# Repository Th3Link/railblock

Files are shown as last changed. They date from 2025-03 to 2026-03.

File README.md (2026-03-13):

# RailBlock

[]()
[]()

**RailBlock** is an open hardware CAN‑bus based block detector and
signal controller for model railways.

It is designed to integrate with a **Raspberry Pi running Rocrail**,
providing reliable **track occupancy detection** and **signal control**
using a distributed CAN bus network.

The project consists of:

-   **Hardware** -- KiCad PCB design
-   **Firmware** -- written in **Embedded Rust** using **Embassy** and
    **heapless**

------------------------------------------------------------------------

# Overview

RailBlock modules are connected using a **50 kbit/s CAN bus** carried
over **RJ45 cables**.\
Each board contains:

-   an **ESP32 microcontroller**
-   a **CAN transceiver**
-   inputs for **Hall sensors**
-   outputs for **signal lights**

Multiple boards can be connected in a **daisy-chain topology**,
distributing both **power (12V)** and **CAN communication** over a
single cable.

Typical setup:

    Raspberry Pi (Rocrail)
            │
       CAN Interface
            │
      ───── CAN Bus ─────
         │       │       │
     RailBlock RailBlock RailBlock
         │       │       │
     Sensors   Signals  Sensors

------------------------------------------------------------------------

# Features

-   CAN bus communication (**50 kbit/s**)
-   RJ45 bus connectors for **daisy chaining**
-   **Power + data on one cable**
-   Up to **3 Hall sensors** per board
-   Up to **7 signal outputs**
-   **ULN2003A sinking driver**
-   **ESP32 microcontroller**
-   **Embedded Rust firmware**
-   **JTAG debugging support**
-   Designed for **Rocrail integration**

------------------------------------------------------------------------

# Hardware

The hardware design is provided as a **KiCad project**.

Each RailBlock node contains:

-   ESP32 microcontroller
-   CAN transceiver
-   ULN2003A output driver
-   connectors for Hall sensors
-   connectors for signal lights
-   two RJ45 bus connectors

The RJ45 connectors allow the bus to **pass through each board**,
simplifying wiring.

Both **power and CAN signals** are carried through the same cable.

------------------------------------------------------------------------

# RJ45 Bus Pinout

RailBlock uses standard **RJ45 connectors** to distribute **CAN bus and
12V power**.

Multiple pins are paralleled to increase current capacity.

    RJ45 Pinout (RailBlock Bus)

       +-----------------------+
       | 1  2  3  4  5  6  7  8 |
       +-----------------------+

    Pin 1  ── GND
    Pin 2  ── GND
    Pin 3  ── GND

    Pin 4  ── CANH
    Pin 5  ── CANL

    Pin 6  ── +12V
    Pin 7  ── +12V
    Pin 8  ── +12V

Notes:

-   Pins **4 and 5 form a twisted pair** in standard Ethernet cables
    (blue / blue‑white).
-   Pins **1--3 and 6--8 are bundled** to increase current carrying
    capacity.
-   This allows moderate **power distribution along the bus**.

------------------------------------------------------------------------

# Bus Topology

RailBlock nodes must be connected in a **linear CAN topology**.

    12V + CAN Bus

    [Terminator] ── RailBlock ── RailBlock ── RailBlock ── [Terminator]

Important:

-   The **first and last node must be terminated**.
-   Termination uses the standard **120 Ω CAN resistor**.

------------------------------------------------------------------------

# Inputs -- Hall Sensors

Each RailBlock board supports **up to 3 Hall sensors** for track
occupancy detection.

Recommended sensor:

-   **TLE4905L**
-   or compatible digital Hall sensors

Typical setup:

-   a small magnet is mounted under a locomotive
-   the Hall sensor detects the magnet
-   the RailBlock node sends an occupancy event

Events are transmitted over CAN using **S88 event messages**.

------------------------------------------------------------------------

# Outputs -- Signals

Each RailBlock board supports **up to 7 signal outputs**.

Outputs are implemented using a **ULN2003A Darlington driver**.

The LED anode connects to **+12V or +5V via a resistor**, while the
RailBlock output sinks current. Some signals have internal resistors.

------------------------------------------------------------------------

# Firmware

The firmware is written in **Embedded Rust**.

Technologies used:

-   **Embassy** async runtime
-   **heapless** containers (no dynamic allocation)
-   **esp-hal**

Design goals:

-   deterministic behaviour
-   low memory usage
-   robust CAN communication

------------------------------------------------------------------------

# CAN Protocol

RailBlock communicates over CAN using two protocol types.

## Märklin CS2 Accessory Protocol

Used for:

-   signal control
-   accessory commands

## S88 Event Messages

Used to report:

-   Hall sensor triggers
-   block occupancy events

------------------------------------------------------------------------

# Programming and Debugging

The ESP32 firmware can be uploaded using:

### Programming Adapter

A dedicated **programming adapter** (separate project).

### JTAG

The board also supports **JTAG debugging**, allowing:

-   breakpoints
-   single stepping
-   real runtime debugging

------------------------------------------------------------------------

# Integration with Rocrail

RailBlock is designed to work with **Rocrail** running on a **Raspberry
Pi**.

Typical architecture:

    Raspberry Pi
       (Rocrail)
           │
       CAN Interface
           │
      ───── CAN Bus ─────
         │       │       │
     RailBlock RailBlock RailBlock
         │       │       │
     Sensors   Signals  Sensors

Rocrail can:

-   receive **occupancy events**
-   control **signals and accessories**

------------------------------------------------------------------------

# Repository Structure

    railblock/
    │
    ├─ firmware/        Embedded Rust firmware
    │
    ├─ hardware/        KiCad PCB design
    │
    ├─ docs/            Documentation
    │
    └─ README.md

------------------------------------------------------------------------

# Licensing

This repository contains both **hardware designs** and **software**.

## Firmware

Licensed under:

**GNU General Public License v3 (GPLv3)**

See:

    firmware/LICENSE.txt

## Hardware

Licensed under:

**CERN Open Hardware Licence Version 2 -- Strongly Reciprocal
(CERN-OHL-S-2.0)**

See:

    hardware/LICENSE.txt

------------------------------------------------------------------------

# Status

Early development.

Hardware and firmware are evolving together.

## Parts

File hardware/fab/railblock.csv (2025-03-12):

MPN |  | Manufacturer | Quantity | Designation
MCP1703A-5002E/DB | 500053801 | Microchip Technology | 1 | MCP1703Ax-500xxDB | U6
MCP1703A-3302E/DB | 500053800 | Microchip Technology | 1 | MCP1703Ax-330xxDB | U5
ULN2003A | 501429305 | UMW | 1 | ULN2003A | U4
ESP32-WROOM-32E-N4 | 500186636 | Espressif Systems | 1 | ESP32-WROOM-32 | U3
MCP2562-E/SN | 500054071 | Microchip Technology | 1 | MCP2562-E-SN | U2
PESD2CAN | 501716486 | DART | 1 | PESD2CAN | U1
RT0603FRE0727KL | 501355046 | YAGEO | 3 | 27K | R7,R5,R1
AA0603JR-0710KL | 501762420 | YAGEO | 3 | 10K | R6,R3,R2,R4
GRM188R71E104KA01D | 500015875 | Murata | 7 | 100n | C15,C12,C10,C9,C8,C4,C1
CL21B106KPQNNNG | 501368261 | Samsung Electro-Mechanics | 5 | 10u | C14,C13,C7,C6,C3
CL10B105KA8NFNC | 500024764 | Samsung Electro-Mechanics | 1 | 1u | C2

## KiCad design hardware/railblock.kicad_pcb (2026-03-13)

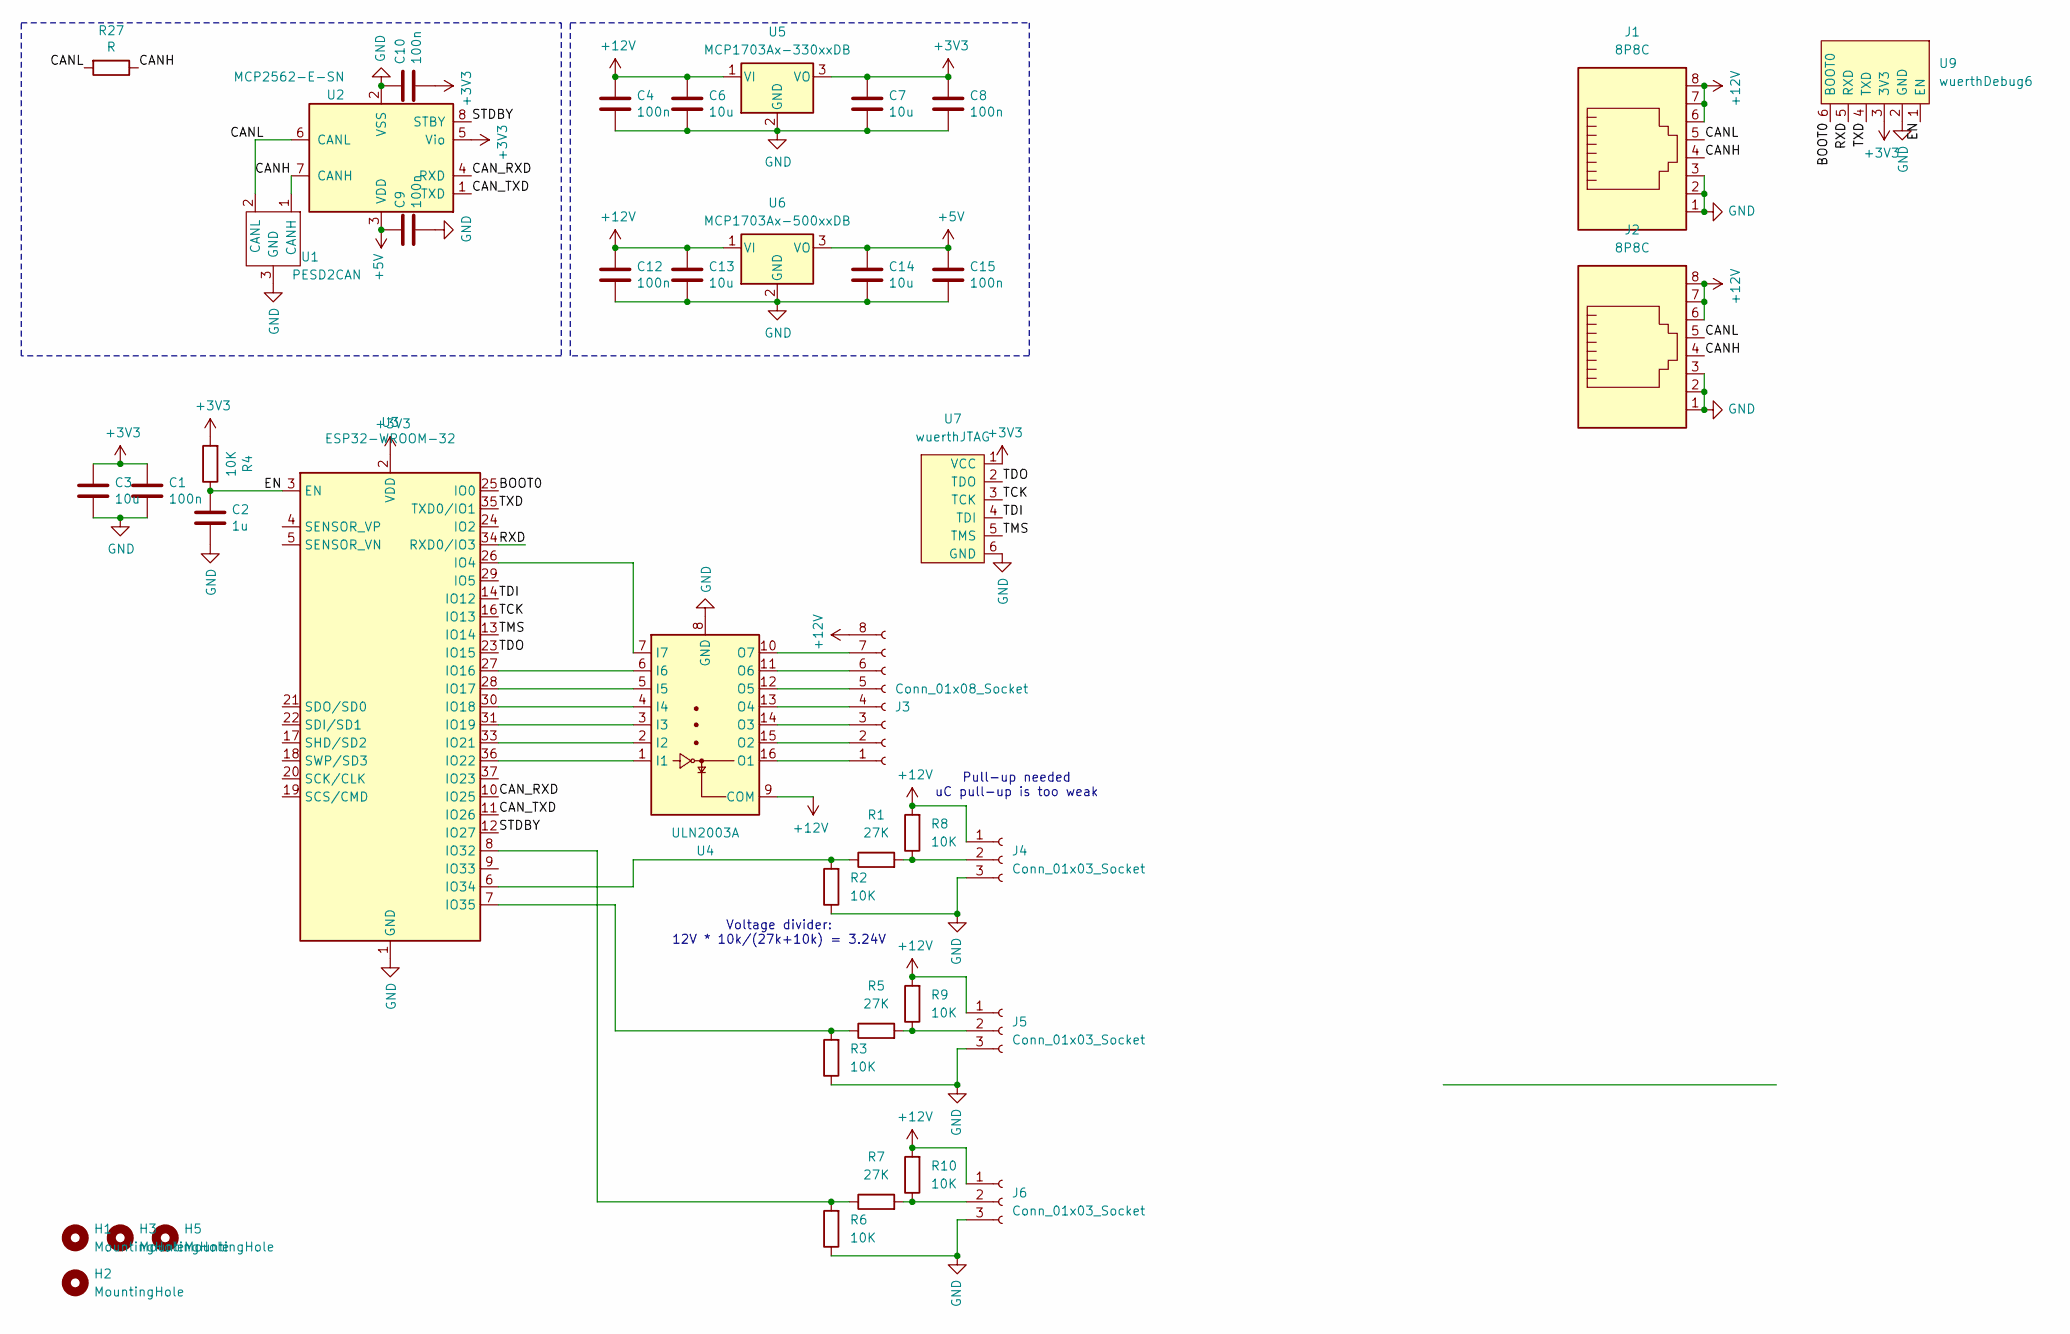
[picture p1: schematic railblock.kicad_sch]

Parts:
C1, C4, C8, C9, C10, C12, C15: 100n; C_0603_1608Metric_Pad1.08x0.95mm_HandSolder
C2: 1u; C_0603_1608Metric_Pad1.08x0.95mm_HandSolder
C3, C6, C7, C13, C14: 10u; C_0805_2012Metric_Pad1.18x1.45mm_HandSolder
H1, H2, H3, H5: MountingHole; MountingHole_3.2mm_M3_DIN965
J1, J2: 8P8C; RJ45_Ninigi_GE
J3: Conn_01x08_Socket; WAGO250-208
J4, J5, J6: Conn_01x03_Socket; WAGO250-203
R1, R5, R7: 27K; R_0603_1608Metric_Pad0.98x0.95mm_HandSolder
R2, R3, R4, R6, R8, R9, R10: 10K; R_0603_1608Metric_Pad0.98x0.95mm_HandSolder
R27: R; R_0603_1608Metric_Pad0.98x0.95mm_HandSolder
U1: PESD2CAN; SOT-23
U2: MCP2562-E-SN; SOIC-8_3.9x4.9mm_P1.27mm
U3: ESP32-WROOM-32
U4: ULN2003A; SOIC-16_3.9x9.9mm_P1.27mm
U5: MCP1703Ax-330xxDB; SOT-223-3_TabPin2
U6: MCP1703Ax-500xxDB; SOT-223-3_TabPin2
U7: wuerthJTAG
U9: wuerthDebug6

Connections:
+3V3: C1.1, C3.1, C7.1, C8.1, C10.1, R4.2, U2.5 (Vio), U3.2 (VDD), U5.3 (VO), U7.1 (VCC), U9.3 (3V3)
+5V: C9.1, C14.1, C15.1, U2.3 (VDD), U6.3 (VO)
+12V: C4.1, C6.1, C12.1, C13.1, J1.6, J1.7, J1.8, J2.6, J2.7, J2.8, J3.8, J4.1, J5.1, J6.1, R8.2, R9.2, R10.2, U4.9 (COM), U5.1 (VI), U6.1 (VI)
/BOOT0: U3.25 (IO0), U9.6 (BOOT0)
/CANH: J1.4, J2.4, R27.1, U1.1 (CANH), U2.7 (CANH)
/CANL: J1.5, J2.5, R27.2, U1.2 (CANL), U2.6 (CANL)
/CAN_RXD: U2.4 (RXD), U3.10 (IO25)
/CAN_TXD: U2.1 (TXD), U3.11 (IO26)
/EN: C2.1, R4.1, U3.3 (EN), U9.1 (EN)
/RXD: U3.34 (RXD0/IO3), U9.5 (RXD)
/STDBY: U2.8 (STBY), U3.12 (IO27)
/TCK: U3.16 (IO13), U7.3 (TCK)
/TDI: U3.14 (IO12), U7.4 (TDI)
/TDO: U3.23 (IO15), U7.2 (TDO)
/TMS: U3.13 (IO14), U7.5 (TMS)
/TXD: U3.35 (TXD0/IO1), U9.4 (TXD)
GND: C1.2, C2.2, C3.2, C4.2, C6.2, C7.2, C8.2, C9.2, C10.2, C12.2, C13.2, C14.2, C15.2, J1.1, J1.2, J1.3, J2.1, J2.2, J2.3, J4.3, J5.3, J6.3, R2.1, R3.1, R6.1, U1.3 (GND), U2.2 (VSS), U3.1 (GND), U3.15 (GND), U3.38 (GND), U3.39 (GND), U4.8 (GND), U5.2 (GND), U6.2 (GND), U7.6 (GND), U9.2 (GND)
unnamed: J3.1, U4.16 (O1)
unnamed: J3.2, U4.15 (O2)
unnamed: J3.3, U4.14 (O3)
unnamed: J3.4, U4.13 (O4)
unnamed: J3.5, U4.12 (O5)
unnamed: J3.6, U4.11 (O6)
unnamed: J3.7, U4.10 (O7)
unnamed: J4.2, R1.2, R8.1
unnamed: J5.2, R5.2, R9.1
unnamed: J6.2, R7.2, R10.1
unnamed: U3.26 (IO4), U4.7 (I7)
unnamed: U3.27 (IO16), U4.6 (I6)
unnamed: U3.28 (IO17), U4.5 (I5)
unnamed: U3.30 (IO18), U4.4 (I4)
unnamed: U3.31 (IO19), U4.3 (I3)
unnamed: U3.33 (IO21), U4.2 (I2)
unnamed: U3.36 (IO22), U4.1 (I1)
unnamed: R6.2, R7.1, U3.8 (IO32)
unnamed: R1.1, R2.2, U3.6 (IO34)
unnamed: R3.2, R5.1, U3.7 (IO35)

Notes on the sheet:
Voltage divider: 12V * 10k/(27k+10k) = 3.24V
Pull-up needed uC pull-up is too weak

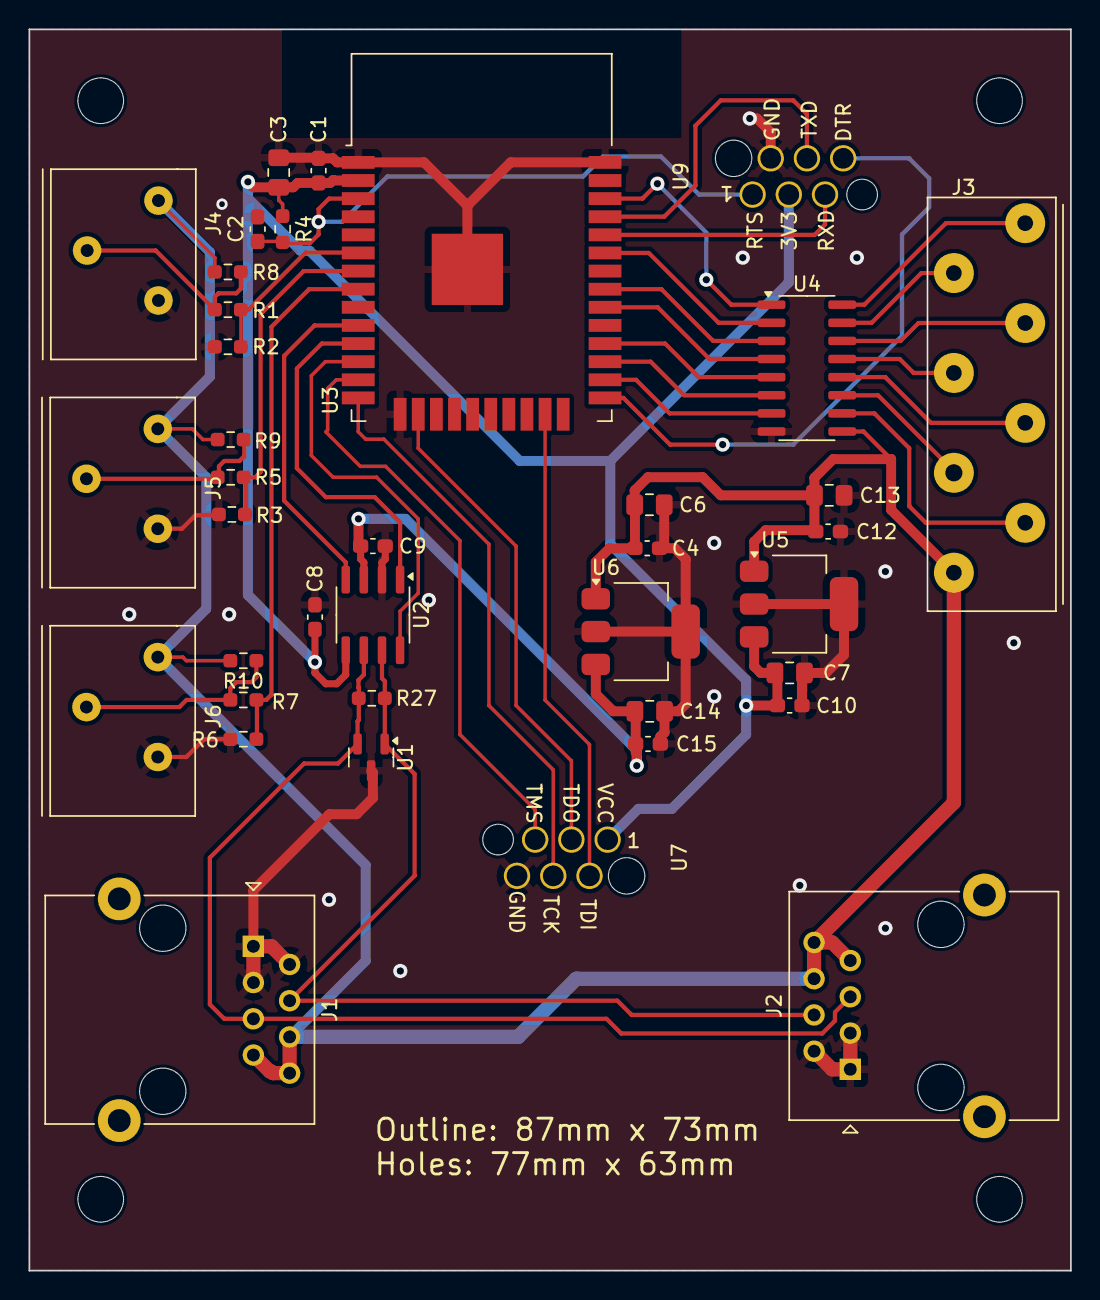
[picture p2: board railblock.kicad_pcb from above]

Board: 2 copper layers, 73.0 x 87.0 mm, 42 parts (0 on the bottom side), 37 nets.

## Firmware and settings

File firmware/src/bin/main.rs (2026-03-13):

#![no_std]
#![no_main]

use core::panic::PanicInfo;
use embassy_executor::Spawner;
use embassy_time::Duration;
use embassy_time::Timer;
use esp_backtrace as _;
use esp_hal::clock::CpuClock;
use esp_hal::timer::timg::TimerGroup;
use esp_hal_embassy::main;
use esp_println::println;
use railblock::accessory;
use railblock::button;
use railblock::can;
use railblock::cli;
use railblock::config;
use railblock::gpio_interrupt;

#[panic_handler]
fn panic(_info: &PanicInfo) -> ! {
    esp_hal::system::software_reset();
}

#[main]
async fn main(spawner: Spawner) -> ! {
    let peripherals = esp_hal::init(esp_hal::Config::default().with_cpu_clock(CpuClock::_80MHz));

    let timg0 = TimerGroup::new(peripherals.TIMG0);
    esp_hal_embassy::init(timg0.timer0);
    println!("starting railblock");
    config::init().await;

    if let Some(device_id) = config::config().await.get_u8(config::Key::DeviceId).await {
        println!("loaded device_id {device_id}");
    }

    button::init(
        peripherals.GPIO33,
        peripherals.GPIO25,
        peripherals.GPIO26,
        &spawner,
    );
    gpio_interrupt::init(peripherals.IO_MUX);
    can::init(
        peripherals.TWAI0,
        peripherals.GPIO14,
        peripherals.GPIO13,
        peripherals.GPIO15,
        &spawner,
    )
    .await;
    accessory::init(
        peripherals.GPIO22,
        peripherals.GPIO21,
        peripherals.GPIO19,
        peripherals.GPIO18,
        peripherals.GPIO17,
        peripherals.GPIO16,
        peripherals.GPIO4,
        &spawner,
    );
    Timer::after(Duration::from_millis(2_000)).await;
    cli::init(
        peripherals.UART0,
        peripherals.GPIO3,
        peripherals.GPIO1,
        &spawner,
    )
    .await;
    loop {
        Timer::after(Duration::from_millis(3_000)).await;
    }
}

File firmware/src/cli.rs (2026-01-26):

use core::str::FromStr;
use embassy_executor::Spawner;
use embassy_sync::blocking_mutex::raw::CriticalSectionRawMutex;
use embassy_sync::channel::Channel;
use esp_hal::Async;
use esp_hal::gpio::{InputPin, OutputPin};
use esp_hal::uart;
use esp_println::println;
use heapless::String;
use heapless::Vec;

use crate::config::{self, config};

pub static UART_CHANNEL: Channel<CriticalSectionRawMutex, String<100>, 4> = Channel::new();

pub async fn init(
    uart: esp_hal::peripherals::UART0<'static>,
    rx: impl InputPin + 'static,
    tx: impl OutputPin + 'static,
    spawner: &Spawner,
) {
    let uart = uart::Uart::new(uart, uart::Config::default())
        .unwrap()
        .with_rx(rx)
        .with_tx(tx)
        .into_async();

    let (rx, tx) = uart.split();

    spawner.spawn(uart_send_task(tx)).unwrap();
    spawner.spawn(uart_recieve_task(rx)).unwrap();
}

async fn handle_line(line: &str) -> Option<String<100>> {
    let parts: Vec<&str, 8> = line.split_whitespace().collect();

    if parts.is_empty() {
        return None;
    }

    match parts[0] {
        "device_id" => cmd_device_id(&parts[1..]).await,
        "help" => Some(help_text()),
        _ => Some(str_msg("unknown command\r\n")),
    }
}

async fn cmd_device_id(args: &[&str]) -> Option<String<100>> {
    if args.len() != 1 {
        return Some(str_msg("usage: device_id <u8>\r\n"));
    }

    match u8::from_str(args[0]) {
        Ok(id) => {
            // 👉 deine echte Logik
            config()
                .await
                .set_u8(config::Key::DeviceId, id)
                .await
                .unwrap();
            let mut msg: heapless::String<100> = heapless::String::new();
            let _ = msg.push_str("device id set: ");
            crate::helper::write_u8(&mut msg, id).ok();
            let _ = msg.push_str("\r\n");

            Some(msg)
        }
        Err(_) => Some(str_msg("invalid number\r\n")),
    }
}

fn str_msg(s: &str) -> String<100> {
    let mut out = String::new();
    let _ = out.push_str(s);
    out
}

fn help_text() -> String<100> {
    str_msg(
        "commands:\r\n\
         device_id <u8>\r\n\
         help\r\n",
    )
}

pub async fn dispatch(rx_buf: &[u8], line: &mut String<100>) {
    for &byte in rx_buf {
        match byte {
            b'\r' | b'\n' => {
                // Zeilenende → sende Zeile an Channel
                if !line.is_empty() {
                    if let Some(resp) = handle_line(line.as_str()).await {
                        UART_CHANNEL.send(resp).await;
                    }
                    line.clear();
                }
                UART_CHANNEL.send(str_msg("> ")).await; // Prompt
            }

            0x08 | 0x7F => {
                // Backspace
                line.pop();
                // Backspace auch zurückschicken, damit Terminal korrekt löscht
                let mut bs = heapless::String::<100>::new();
                let _ = bs.push_str("\x08 \x08");
                UART_CHANNEL.send(bs).await;
            }

            _ => {
                // Normales Zeichen → in Line puffern + echo
                if line.push(byte as char).is_ok() {
                    let mut echo = heapless::String::<100>::new();
                    let _ = echo.push(byte as char);
                    UART_CHANNEL.send(echo).await;
                }
            }
        }
    }
}
/*
async fn dispatch(rx_buf: &[u8], n: usize, line: &mut String<100>) {
    for &byte in &rx_buf[..n] {
        match byte {
            b'\r' | b'\n' => {
                if !line.is_empty() {
                    if let Some(resp) = handle_line(line.as_str()).await {
                        UART_CHANNEL.send(resp).await;
                    }
                    line.clear();
                }
                UART_CHANNEL.send(str_msg("> ")).await;
            }

            0x08 | 0x7F => {
                line.pop();
            }

            _ => {
                let _ = line.push(byte as char);
            }
        }
    }
}
*/
#[embassy_executor::task]
pub async fn uart_recieve_task(mut rx: uart::UartRx<'static, Async>) {
    println!("uart_recieve_task started");
    let mut rx_buf = [0u8; 32];
    let mut line: String<100> = String::new();
    loop {
        if let Ok(bytes) = rx.read_async(&mut rx_buf).await {
            dispatch(&rx_buf[..bytes], &mut line).await;
        } else {
            println!("recv error");
        }
    }
}

#[embassy_executor::task]
pub async fn uart_send_task(mut tx: uart::UartTx<'static, Async>) {
    println!("uart_send_task started");
    loop {
        let line = UART_CHANNEL.receive().await;
        tx.write_async(line.as_bytes()).await.unwrap();
    }
}

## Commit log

2025-03-12 feat: Add initial files
    [partitions.csv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]
2025-03-24 feat: Add devicetype
2026-01-01 feat: Make hall and relais working
    [railblock.kicad_pcb, railblock.kicad_sch]
2026-01-26 feat: Move implementation to rust
    [partitions.csv]
2026-03-13 fix: Adapt accessory and S88 data format
    [accessory.rs, button.rs, main.rs]
2026-03-13 fix: Add pull-up for hall sensors
    [railblock.kicad_pcb, railblock.kicad_sch]
2026-03-13 feat: Add JTAG interface
    [railblock.kicad_pcb, railblock.kicad_sch]
2026-03-13 feat: Bring more structure into the project
    [partitions.csv, railblock.kicad_sch]

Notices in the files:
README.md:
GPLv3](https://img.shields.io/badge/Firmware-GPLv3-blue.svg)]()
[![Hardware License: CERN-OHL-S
